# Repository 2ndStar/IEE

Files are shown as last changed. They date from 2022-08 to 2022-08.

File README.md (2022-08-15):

This is a PCB project for a 60% + XT column keyboard. It has a very specific fixed layout
1. Fixed split backspace
2. Fixed bottom row: 1.5u 1.25u 1.5u 2.75u 2.25u 1.5u 1.5u 1.25u 1.5u

There is a small issue with the "KC_Grave" key located at Row1 Column8.
Take a look at the schematic and fix it for yourself.

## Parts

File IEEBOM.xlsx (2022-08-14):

Comment | Designator | Footprint | LCSC Part # (Optional)
100nF | C3, C5, C6 | 805 | C49678
1uF | C4 | 805 | C28323
10uF | C7 | 805 | C15850
10K | R3, R4 | 805 | C17414
22 | R1, R2 | 805 | C17561
SWITCHING DIODE | D1,D2,D3,D4,D5,D6,D7,D8,D9,D10,D11,D12,D13,D14,D15,D16,D17,D18,D19,D20,D21,D22,D23,D24,D25,D26,D27,D28,D29,D30,D31,D32,D33,D34,D35,D36,D37,D38,D39,D40,D41,D42,D43,D44,D45,D46,D47,D48,D49,D50,D51,D52,D53,D54,D55,D56,D57,D58,D59,D60,D61,D62,D63,D64,D65,D66,D67,D68,D69,D70,D71,D72,D73,D74 | SOD-123 | C81598
16MHz | Y1 | 3225 | C13738
500mA | F1 | 1206 | C70076
22pF | C1, C2 | 805 | C1804
Button | SW1 | smdPushBtn | C318884
SM04B-SRSS-TB | J1 | SM04B-SRSS-TB | C371571
SRV05-4 | U2 | SOT-23-6L | C85364
500 | R5 | 805 | C2828857
1N4001W | D75 | SOD-123F | C162732
2.2k | R6 | 805 | C17520

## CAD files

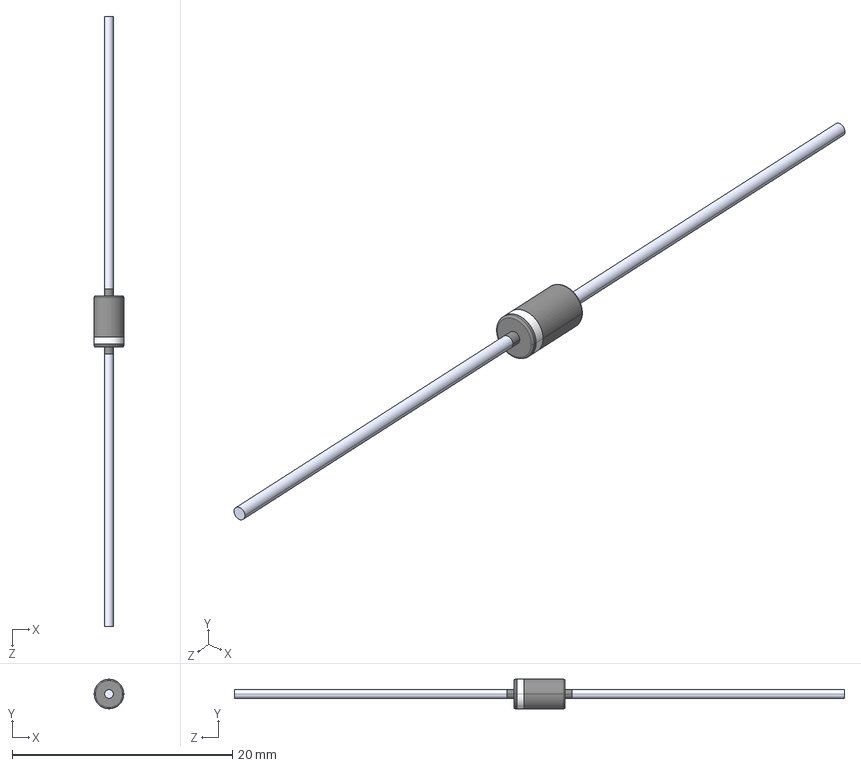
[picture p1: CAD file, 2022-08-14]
1N4001-T/1N4001-T.step
2.69 x 2.69 x 55.4 mm

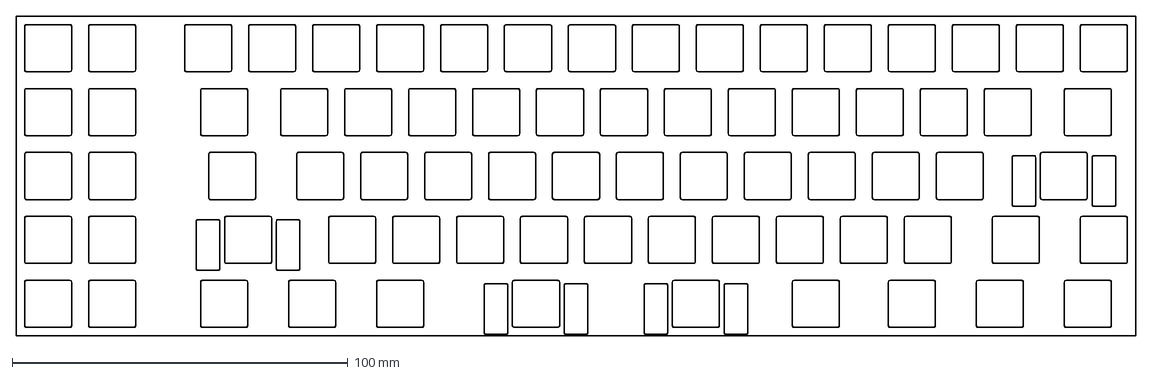
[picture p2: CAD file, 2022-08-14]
plateguide.dxf
333.4 x 95.2 mm

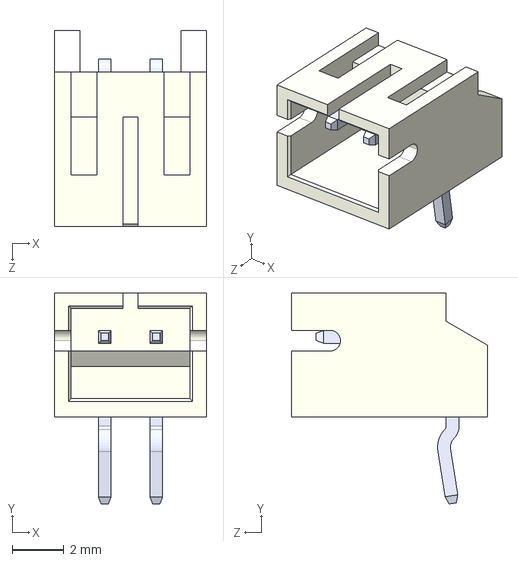
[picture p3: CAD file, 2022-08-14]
S2B-PH-K-S_LF__SN_/S2B-PH-K-S_LF__SN_.step
5.90 x 8.18 x 7.60 mm

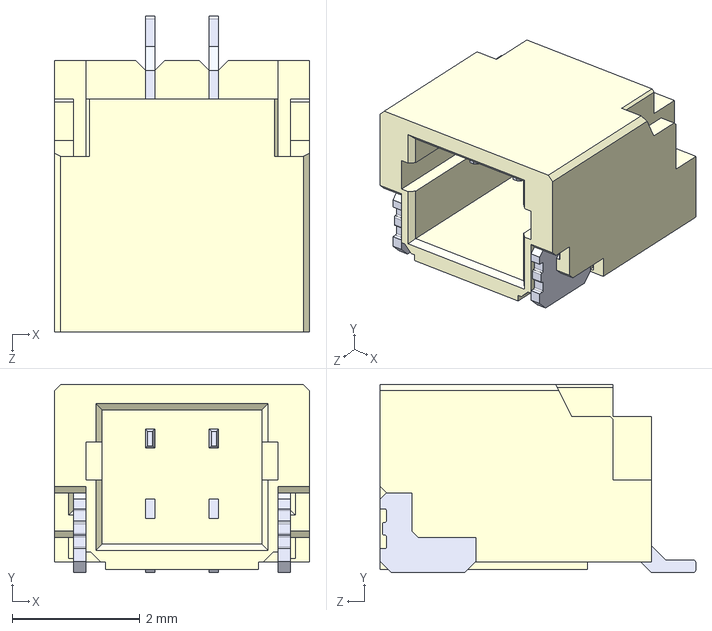
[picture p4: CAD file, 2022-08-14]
SM02B-SRSS-TB_LF__SN_/SM02B-SRSS-TB_LF__SN_.step
4.00 x 2.95 x 4.95 mm

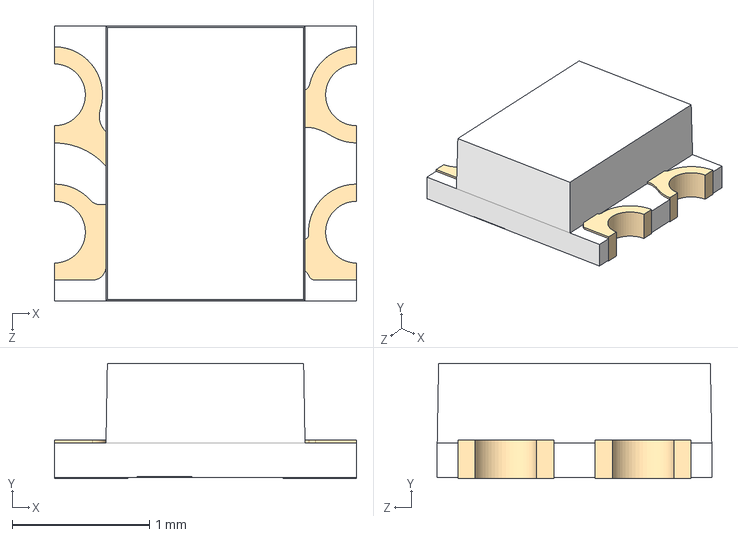
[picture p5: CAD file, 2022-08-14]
WS2812-2020/WS2812-2020.step
2.20 x 0.84 x 2.00 mm

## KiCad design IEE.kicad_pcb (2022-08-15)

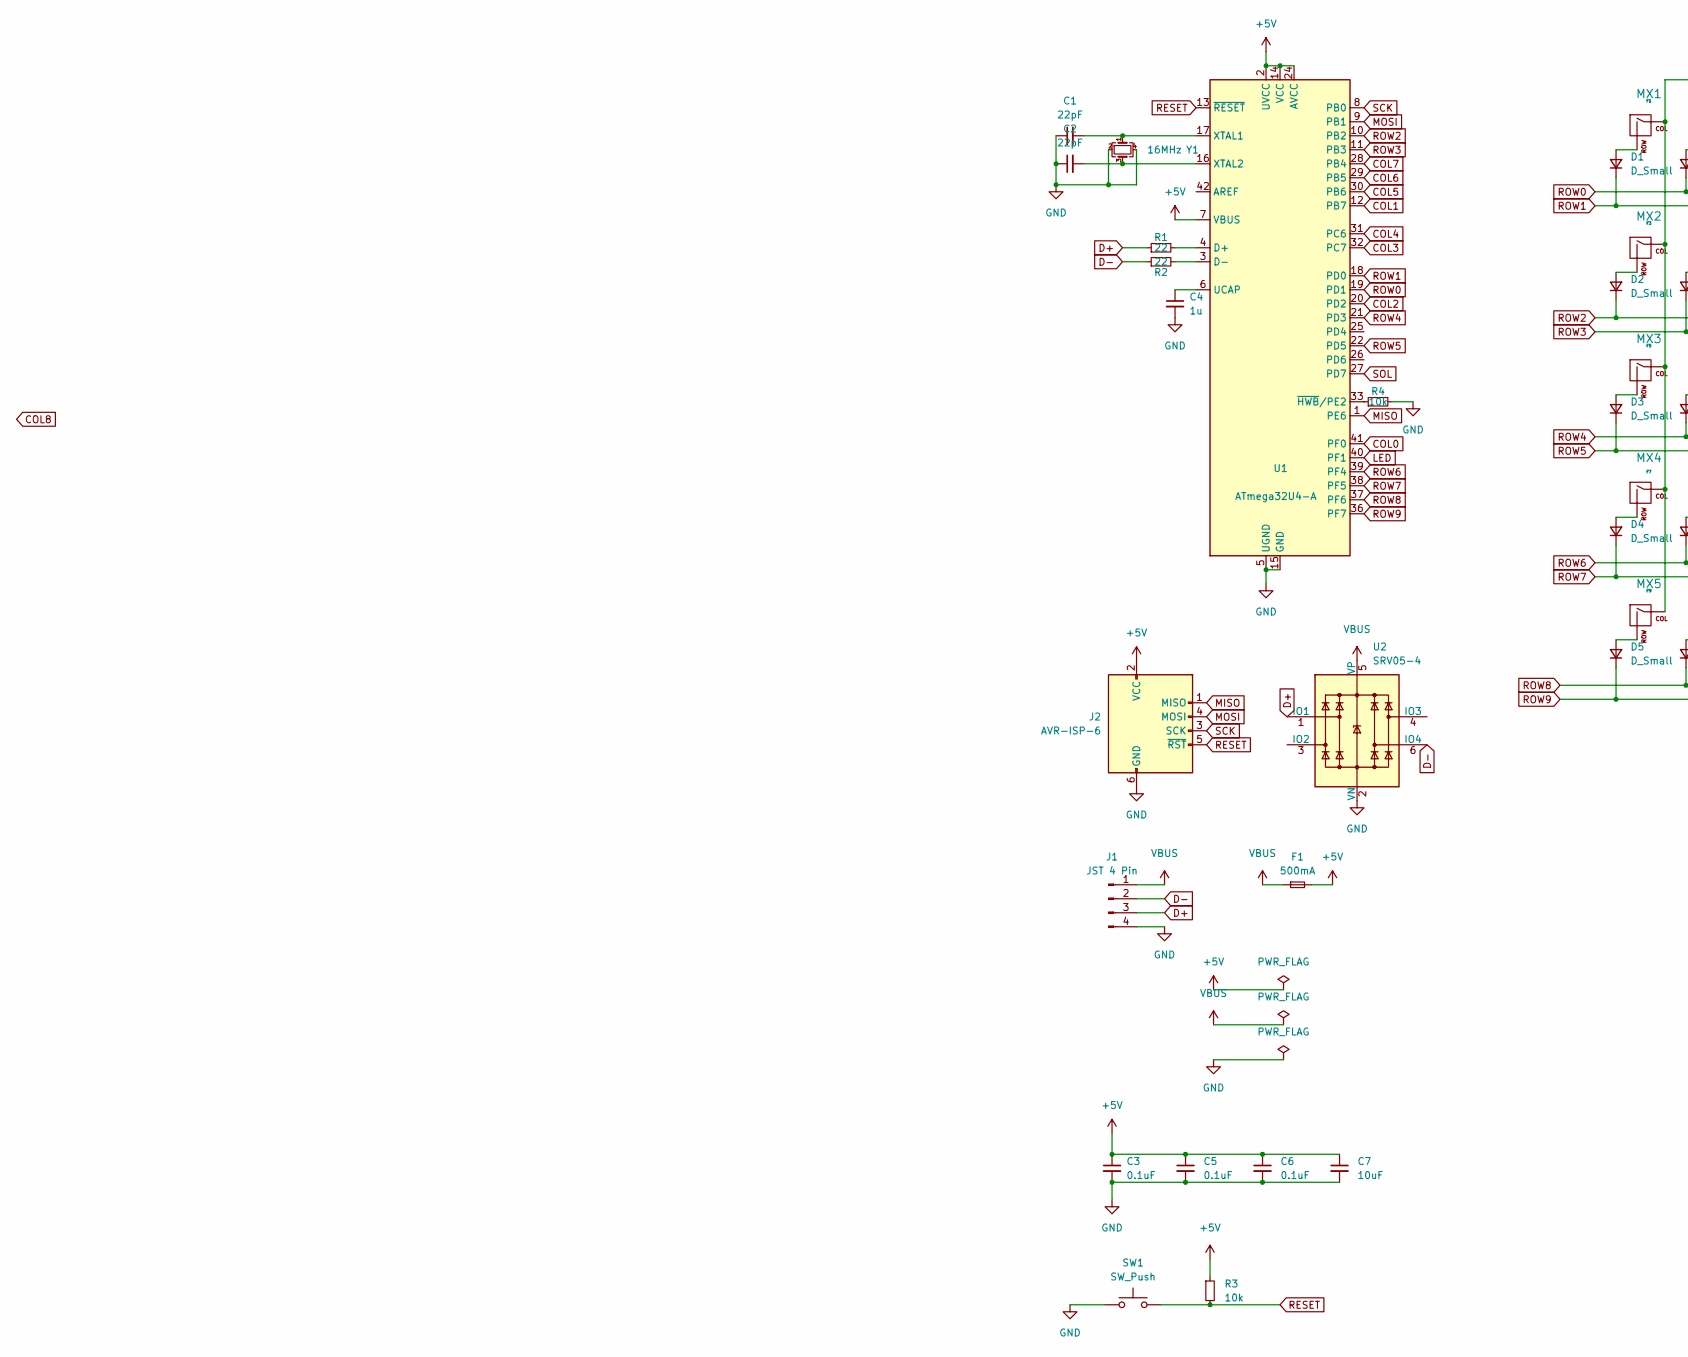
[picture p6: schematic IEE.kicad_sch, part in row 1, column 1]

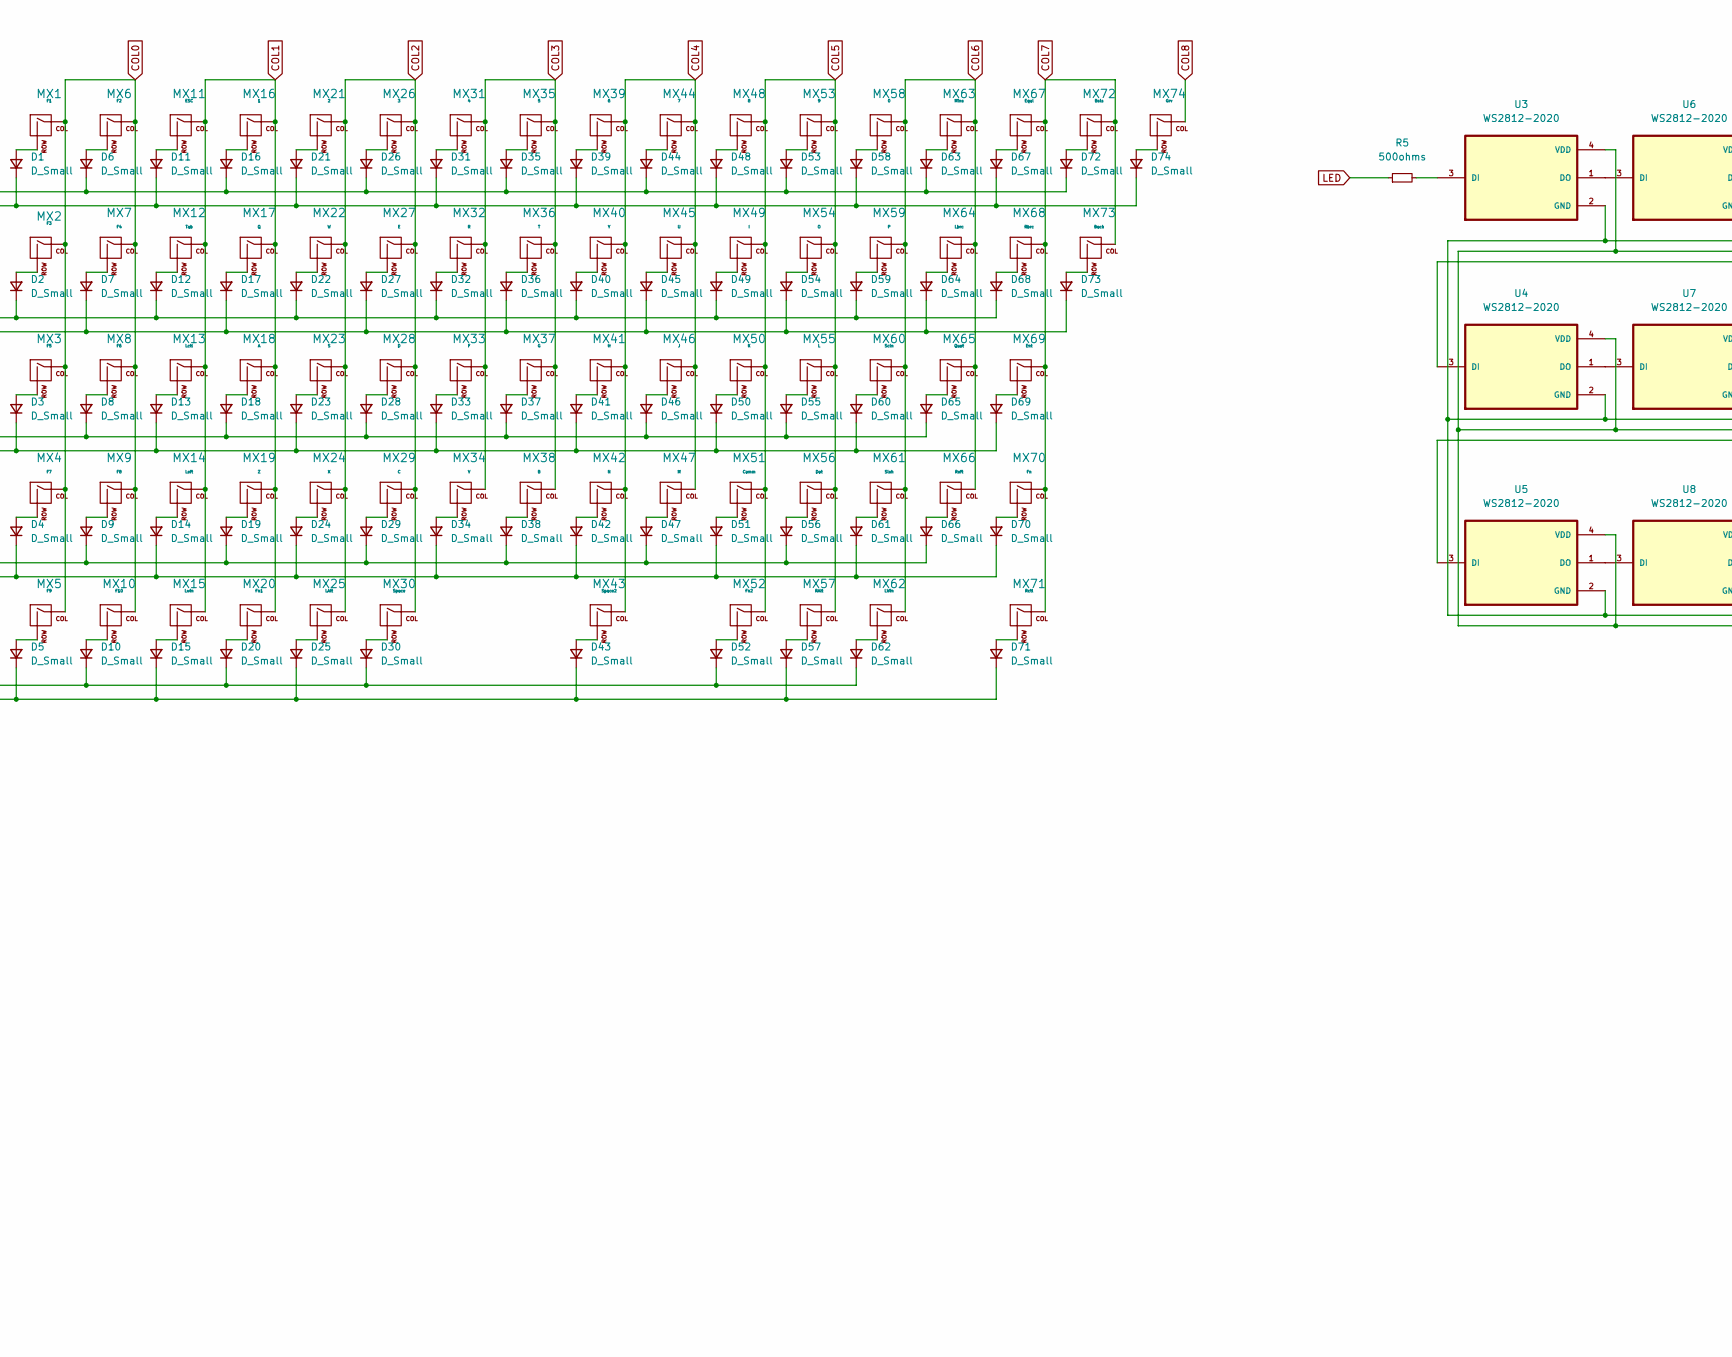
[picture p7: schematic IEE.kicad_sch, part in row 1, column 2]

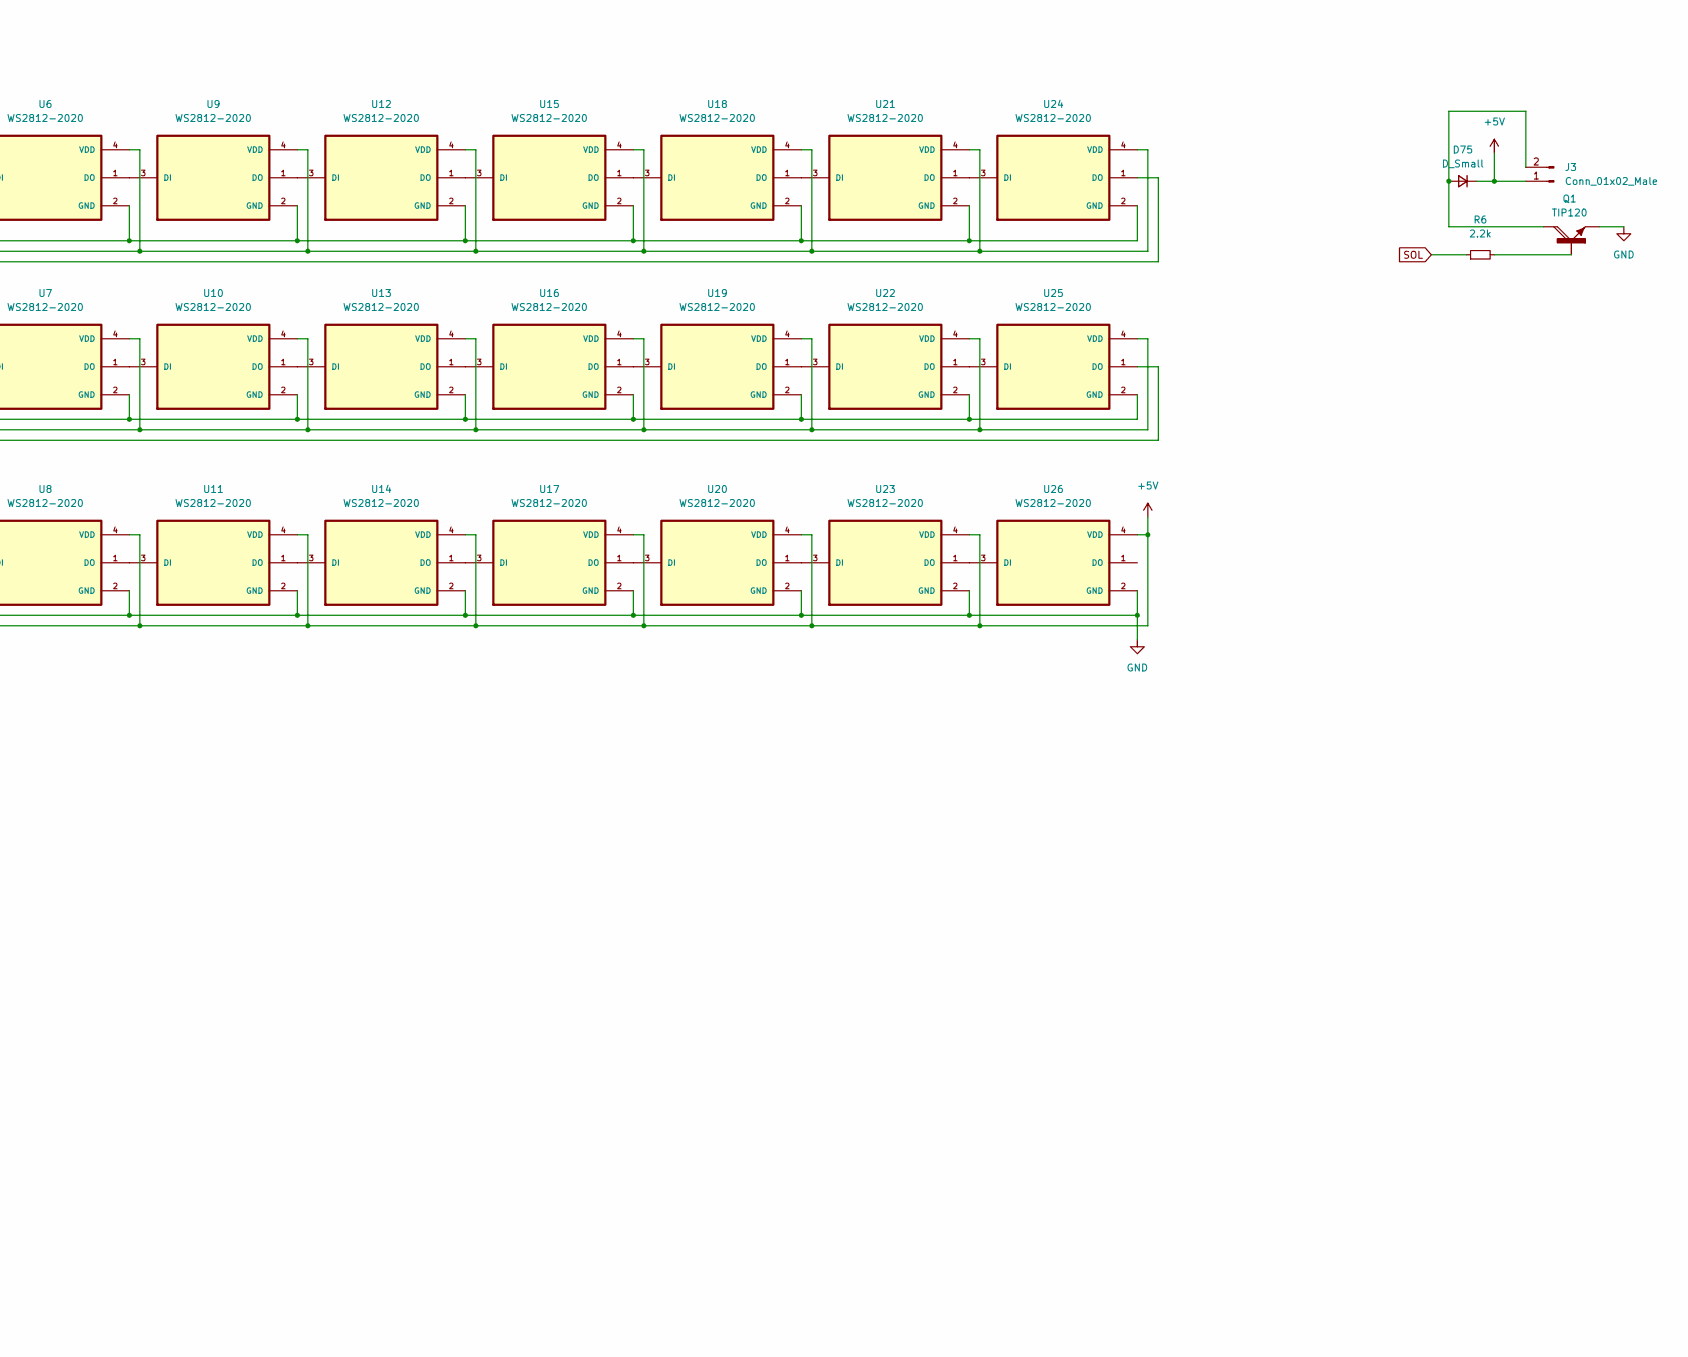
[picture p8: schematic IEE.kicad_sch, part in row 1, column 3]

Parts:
C1, C2: 22pF; C_0805_2012Metric
C3, C5, C6: 0.1uF; C_0805_2012Metric
C4: 1u; C_0805_2012Metric
C7: 10uF; C_0805_2012Metric
D1, D2, D3, D4, D5, D6, D7, D8, D9, D10, D11, D12, D13, D14, D15, D16, D17, D18, D19, D20, D21, D22, D23, D24, D25, D26, D27, D28, D29, D30, D31, D32, D33, D34, D35, D36, D37, D38, D39, D40, D41, D42, D43, D44, D45, D46, D47, D48, D49, D50, D51, D52, D53, D54, D55, D56, D57, D58, D59, D60, D61, D62, D63, D64, D65, D66, D67, D68, D69, D70, D71, D72, D73, D74: D_Small; D_SOD-123
D75: D_Small; D_SOD-123F
F1: 500mA; Fuse_1206_3216Metric
J1: JST 4 Pin; JST-SR-4
J2: AVR-ISP-6; ISP
J3: Conn_01x02_Male; JST_S2B-PH-K-S(LF)(SN)
MX1: F1; MXOnly-1U-NoLED
MX2: F3; MXOnly-1U-NoLED
MX3: F5; MXOnly-1U-NoLED
MX4: F7; MXOnly-1U-NoLED
MX5: F9; MXOnly-1U-NoLED
MX6: F2; MXOnly-1U-NoLED
MX7: F4; MXOnly-1U-NoLED
MX8: F6; MXOnly-1U-NoLED
MX9: F8; MXOnly-1U-NoLED
MX10: F10; MXOnly-1U-NoLED
MX11: ESC; MXOnly-1U-NoLED
MX12: Tab; MXOnly-1.5U-NoLED
MX13: Lctl; MXOnly-1.75U-NoLED
MX14: Lsft; MXOnly-2.25U-NoLED
MX15: Lwin; MXOnly-1.5U-NoLED
MX16: 1; MXOnly-1U-NoLED
MX17: Q; MXOnly-1U-NoLED
MX18: A; MXOnly-1U-NoLED
MX19: Z; MXOnly-1U-NoLED
MX20: Fn1; MXOnly-1.25U-NoLED
MX21: 2; MXOnly-1U-NoLED
MX22: W; MXOnly-1U-NoLED
MX23: S; MXOnly-1U-NoLED
MX24: X; MXOnly-1U-NoLED
MX25: LAlt; MXOnly-1.5U-NoLED
MX26: 3; MXOnly-1U-NoLED
MX27: E; MXOnly-1U-NoLED
MX28: D; MXOnly-1U-NoLED
MX29: C; MXOnly-1U-NoLED
MX30: Space; MXOnly-2.75U-ReversedStabilizers-NoLED
MX31: 4; MXOnly-1U-NoLED
MX32: R; MXOnly-1U-NoLED
MX33: F; MXOnly-1U-NoLED
MX34: V; MXOnly-1U-NoLED
MX35: 5; MXOnly-1U-NoLED
MX36: T; MXOnly-1U-NoLED
MX37: G; MXOnly-1U-NoLED
MX38: B; MXOnly-1U-NoLED
MX39: 6; MXOnly-1U-NoLED
MX40: Y; MXOnly-1U-NoLED
MX41: H; MXOnly-1U-NoLED
MX42: N; MXOnly-1U-NoLED
MX43: Space2; MXOnly-2.25U-ReversedStabilizers-NoLED
MX44: 7; MXOnly-1U-NoLED
MX45: U; MXOnly-1U-NoLED
MX46: J; MXOnly-1U-NoLED
MX47: M; MXOnly-1U-NoLED
MX48: 8; MXOnly-1U-NoLED
MX49: I; MXOnly-1U-NoLED
MX50: K; MXOnly-1U-NoLED
MX51: Comm; MXOnly-1U-NoLED
MX52: Fn2; MXOnly-1.5U-NoLED
MX53: 9; MXOnly-1U-NoLED
MX54: O; MXOnly-1U-NoLED
MX55: L; MXOnly-1U-NoLED
MX56: Dot; MXOnly-1U-NoLED
MX57: RAlt; MXOnly-1.5U-NoLED
MX58: 0; MXOnly-1U-NoLED
MX59: P; MXOnly-1U-NoLED
MX60: Scln; MXOnly-1U-NoLED
MX61: Slsh; MXOnly-1U-NoLED
MX62: LWin; MXOnly-1.25U-NoLED
MX63: Mins; MXOnly-1U-NoLED
MX64: Lbrc; MXOnly-1U-NoLED
MX65: Quot; MXOnly-1U-NoLED
MX66: Rsft; MXOnly-1.75U-NoLED
MX67: Equl; MXOnly-1U-NoLED
MX68: Rbrc; MXOnly-1U-NoLED
MX69: Ent; MXOnly-2.25U-NoLED
MX70: Fn; MXOnly-1U-NoLED
MX71: Rctl; MXOnly-1.5U-NoLED
MX72: Bsls; MXOnly-1U-NoLED
MX73: Back; MXOnly-1.5U-NoLED
MX74: Grv; MXOnly-1U-NoLED
Q1: TIP120; TO220AH
R1, R2: 22; R_0805_2012Metric
R3, R4: 10k; R_0805_2012Metric
R5: 500ohms; R_0805_2012Metric
R6: 2.2k; R_0805_2012Metric
SW1: SW_Push; SKQG-1155865
U1: ATmega32U4-A; TQFP-44_10x10mm_P0.8mm
U2: SRV05-4; SOT-23-6
U3, U4, U5, U6, U7, U8, U9, U10, U11, U12, U13, U14, U15, U16, U17, U18, U19, U20, U21, U22, U23, U24, U25, U26: WS2812-2020; LED_WS2812-2020
Y1: 16MHz; Crystal_SMD_3225-4Pin_3.2x2.5mm

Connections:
+5V: C3.1, C5.1, C6.1, C7.1, D75.1 (K), F1.2, J2.2 (VCC), J3.1, R3.1, U1.2 (UVCC), U1.7 (VBUS), U1.14 (VCC), U1.24 (AVCC), U1.34 (VCC), U1.44 (AVCC), U3.4 (VDD), U4.4 (VDD), U5.4 (VDD), U6.4 (VDD), U7.4 (VDD), U8.4 (VDD), U9.4 (VDD), U10.4 (VDD), U11.4 (VDD), U12.4 (VDD), U13.4 (VDD), U14.4 (VDD), U15.4 (VDD), U16.4 (VDD), U17.4 (VDD), U18.4 (VDD), U19.4 (VDD), U20.4 (VDD), U21.4 (VDD), U22.4 (VDD), U23.4 (VDD), U24.4 (VDD), U25.4 (VDD), U26.4 (VDD)
COL0: MX1.1 (COL), MX2.1 (COL), MX3.1 (COL), MX4.1 (COL), MX5.1 (COL), MX6.1 (COL), MX7.1 (COL), MX8.1 (COL), MX9.1 (COL), MX10.1 (COL), U1.41 (PF0)
COL1: MX11.1 (COL), MX12.1 (COL), MX13.1 (COL), MX14.1 (COL), MX15.1 (COL), MX16.1 (COL), MX17.1 (COL), MX18.1 (COL), MX19.1 (COL), MX20.1 (COL), U1.12 (PB7)
COL2: MX21.1 (COL), MX22.1 (COL), MX23.1 (COL), MX24.1 (COL), MX25.1 (COL), MX26.1 (COL), MX27.1 (COL), MX28.1 (COL), MX29.1 (COL), MX30.1 (COL), U1.20 (PD2)
COL3: MX31.1 (COL), MX32.1 (COL), MX33.1 (COL), MX34.1 (COL), MX35.1 (COL), MX36.1 (COL), MX37.1 (COL), MX38.1 (COL), U1.32 (PC7)
COL4: MX39.1 (COL), MX40.1 (COL), MX41.1 (COL), MX42.1 (COL), MX43.1 (COL), MX44.1 (COL), MX45.1 (COL), MX46.1 (COL), MX47.1 (COL), U1.31 (PC6)
COL5: MX48.1 (COL), MX49.1 (COL), MX50.1 (COL), MX51.1 (COL), MX52.1 (COL), MX53.1 (COL), MX54.1 (COL), MX55.1 (COL), MX56.1 (COL), MX57.1 (COL), U1.30 (PB6)
COL6: MX58.1 (COL), MX59.1 (COL), MX60.1 (COL), MX61.1 (COL), MX62.1 (COL), MX63.1 (COL), MX64.1 (COL), MX65.1 (COL), MX66.1 (COL), U1.29 (PB5)
COL7: MX67.1 (COL), MX68.1 (COL), MX69.1 (COL), MX70.1 (COL), MX71.1 (COL), MX72.1 (COL), MX73.1 (COL), U1.28 (PB4)
COL8: MX74.1 (COL)
D+: J1.3, R1.1, U2.1 (IO1)
D-: J1.2, R2.1, U2.6 (IO4)
GND: C1.1, C2.1, C3.2, C4.2, C5.2, C6.2, C7.2, J1.4, J2.6 (GND), Q1.E, R4.2, SW1.1, U1.5 (UGND), U1.15 (GND), U1.23 (GND), U1.35 (GND), U1.43 (GND), U2.2 (VN), U3.2 (GND), U4.2 (GND), U5.2 (GND), U6.2 (GND), U7.2 (GND), U8.2 (GND), U9.2 (GND), U10.2 (GND), U11.2 (GND), U12.2 (GND), U13.2 (GND), U14.2 (GND), U15.2 (GND), U16.2 (GND), U17.2 (GND), U18.2 (GND), U19.2 (GND), U20.2 (GND), U21.2 (GND), U22.2 (GND), U23.2 (GND), U24.2 (GND), U25.2 (GND), U26.2 (GND), Y1.2, Y1.4
LED: R5.1, U1.40 (PF1)
MISO: J2.1 (MISO), U1.1 (PE6)
MOSI: J2.4 (MOSI), U1.9 (PB1)
unnamed: C1.2, U1.17 (XTAL1), Y1.1
unnamed: C2.2, U1.16 (XTAL2), Y1.3
unnamed: C4.1, U1.6 (UCAP)
unnamed: D1.2 (A), MX1.2 (ROW)
unnamed: D2.2 (A), MX2.2 (ROW)
unnamed: D3.2 (A), MX3.2 (ROW)
unnamed: D4.2 (A), MX4.2 (ROW)
unnamed: D5.2 (A), MX5.2 (ROW)
unnamed: D6.2 (A), MX6.2 (ROW)
unnamed: D7.2 (A), MX7.2 (ROW)
unnamed: D8.2 (A), MX8.2 (ROW)
unnamed: D9.2 (A), MX9.2 (ROW)
unnamed: D10.2 (A), MX10.2 (ROW)
unnamed: D11.2 (A), MX11.2 (ROW)
unnamed: D12.2 (A), MX12.2 (ROW)
unnamed: D13.2 (A), MX13.2 (ROW)
unnamed: D14.2 (A), MX14.2 (ROW)
unnamed: D15.2 (A), MX15.2 (ROW)
unnamed: D16.2 (A), MX16.2 (ROW)
unnamed: D17.2 (A), MX17.2 (ROW)
unnamed: D18.2 (A), MX18.2 (ROW)
unnamed: D19.2 (A), MX19.2 (ROW)
unnamed: D20.2 (A), MX20.2 (ROW)
unnamed: D21.2 (A), MX21.2 (ROW)
unnamed: D22.2 (A), MX22.2 (ROW)
unnamed: D23.2 (A), MX23.2 (ROW)
unnamed: D24.2 (A), MX24.2 (ROW)
unnamed: D25.2 (A), MX25.2 (ROW)
unnamed: D26.2 (A), MX26.2 (ROW)
unnamed: D27.2 (A), MX27.2 (ROW)
unnamed: D28.2 (A), MX28.2 (ROW)
unnamed: D29.2 (A), MX29.2 (ROW)
unnamed: D30.2 (A), MX30.2 (ROW)
unnamed: D31.2 (A), MX31.2 (ROW)
unnamed: D32.2 (A), MX32.2 (ROW)
unnamed: D33.2 (A), MX33.2 (ROW)
unnamed: D34.2 (A), MX34.2 (ROW)
unnamed: D35.2 (A), MX35.2 (ROW)
unnamed: D36.2 (A), MX36.2 (ROW)
unnamed: D37.2 (A), MX37.2 (ROW)
unnamed: D38.2 (A), MX38.2 (ROW)
unnamed: D39.2 (A), MX39.2 (ROW)
unnamed: D40.2 (A), MX40.2 (ROW)
unnamed: D41.2 (A), MX41.2 (ROW)
unnamed: D42.2 (A), MX42.2 (ROW)
unnamed: D43.2 (A), MX43.2 (ROW)
unnamed: D44.2 (A), MX44.2 (ROW)
unnamed: D45.2 (A), MX45.2 (ROW)
unnamed: D46.2 (A), MX46.2 (ROW)
unnamed: D47.2 (A), MX47.2 (ROW)
unnamed: D48.2 (A), MX48.2 (ROW)
unnamed: D49.2 (A), MX49.2 (ROW)
unnamed: D50.2 (A), MX50.2 (ROW)
unnamed: D51.2 (A), MX51.2 (ROW)
unnamed: D52.2 (A), MX52.2 (ROW)
unnamed: D53.2 (A), MX53.2 (ROW)
unnamed: D54.2 (A), MX54.2 (ROW)
unnamed: D55.2 (A), MX55.2 (ROW)
unnamed: D56.2 (A), MX56.2 (ROW)
unnamed: D57.2 (A), MX57.2 (ROW)
unnamed: D58.2 (A), MX58.2 (ROW)
unnamed: D59.2 (A), MX59.2 (ROW)
unnamed: D60.2 (A), MX60.2 (ROW)
unnamed: D61.2 (A), MX61.2 (ROW)
unnamed: D62.2 (A), MX62.2 (ROW)
unnamed: D63.2 (A), MX63.2 (ROW)
unnamed: D64.2 (A), MX64.2 (ROW)
unnamed: D65.2 (A), MX65.2 (ROW)
unnamed: D66.2 (A), MX66.2 (ROW)
unnamed: D67.2 (A), MX67.2 (ROW)
unnamed: D68.2 (A), MX68.2 (ROW)
unnamed: D69.2 (A), MX69.2 (ROW)
unnamed: D70.2 (A), MX70.2 (ROW)
unnamed: D71.2 (A), MX71.2 (ROW)
unnamed: D72.2 (A), MX72.2 (ROW)
unnamed: D73.2 (A), MX73.2 (ROW)
unnamed: D74.2 (A), MX74.2 (ROW)
unnamed: D75.2 (A), J3.2, Q1.C
unnamed: Q1.B, R6.2
unnamed: R1.2, U1.4 (D+)
unnamed: R2.2, U1.3 (D-)
unnamed: R4.1, U1.33 (~HWB/PE2)
unnamed: R5.2, U3.3 (DI)
unnamed: U3.1 (DO), U6.3 (DI)
unnamed: U4.1 (DO), U7.3 (DI)
unnamed: U5.1 (DO), U8.3 (DI)
unnamed: U6.1 (DO), U9.3 (DI)
unnamed: U10.1 (DO), U13.3 (DI)
unnamed: U7.1 (DO), U10.3 (DI)
unnamed: U11.1 (DO), U14.3 (DI)
unnamed: U8.1 (DO), U11.3 (DI)
unnamed: U12.1 (DO), U15.3 (DI)
unnamed: U9.1 (DO), U12.3 (DI)
unnamed: U13.1 (DO), U16.3 (DI)
unnamed: U14.1 (DO), U17.3 (DI)
unnamed: U15.1 (DO), U18.3 (DI)
unnamed: U16.1 (DO), U19.3 (DI)
unnamed: U17.1 (DO), U20.3 (DI)
unnamed: U18.1 (DO), U21.3 (DI)
unnamed: U19.1 (DO), U22.3 (DI)
unnamed: U20.1 (DO), U23.3 (DI)
unnamed: U21.1 (DO), U24.3 (DI)
unnamed: U22.1 (DO), U25.3 (DI)
unnamed: U23.1 (DO), U26.3 (DI)
unnamed: U4.3 (DI), U24.1 (DO)
unnamed: U5.3 (DI), U25.1 (DO)
RESET: J2.5 (~RST), R3.2, SW1.2, U1.13 (~RESET)
ROW0: D6.1 (K), D16.1 (K), D26.1 (K), D35.1 (K), D44.1 (K), D53.1 (K), D63.1 (K), D72.1 (K), U1.19 (PD1)
ROW1: D1.1 (K), D11.1 (K), D21.1 (K), D31.1 (K), D39.1 (K), D48.1 (K), D58.1 (K), D67.1 (K), D74.1 (K), U1.18 (PD0)
ROW2: D2.1 (K), D12.1 (K), D22.1 (K), D32.1 (K), D40.1 (K), D49.1 (K), D59.1 (K), D68.1 (K), U1.10 (PB2)
ROW3: D7.1 (K), D17.1 (K), D27.1 (K), D36.1 (K), D45.1 (K), D54.1 (K), D64.1 (K), D73.1 (K), U1.11 (PB3)
ROW4: D8.1 (K), D18.1 (K), D28.1 (K), D37.1 (K), D46.1 (K), D55.1 (K), D65.1 (K), U1.21 (PD3)
ROW5: D3.1 (K), D13.1 (K), D23.1 (K), D33.1 (K), D41.1 (K), D50.1 (K), D60.1 (K), D69.1 (K), U1.22 (PD5)
ROW6: D9.1 (K), D19.1 (K), D29.1 (K), D38.1 (K), D47.1 (K), D56.1 (K), D66.1 (K), U1.39 (PF4)
ROW7: D4.1 (K), D14.1 (K), D24.1 (K), D34.1 (K), D42.1 (K), D51.1 (K), D61.1 (K), D70.1 (K), U1.38 (PF5)
ROW8: D10.1 (K), D20.1 (K), D30.1 (K), D52.1 (K), D62.1 (K), U1.37 (PF6)
ROW9: D5.1 (K), D15.1 (K), D25.1 (K), D43.1 (K), D57.1 (K), D71.1 (K), U1.36 (PF7)
SCK: J2.3 (SCK), U1.8 (PB0)
SOL: R6.1, U1.27 (PD7)
VBUS: F1.1, J1.1, U2.5 (VP)

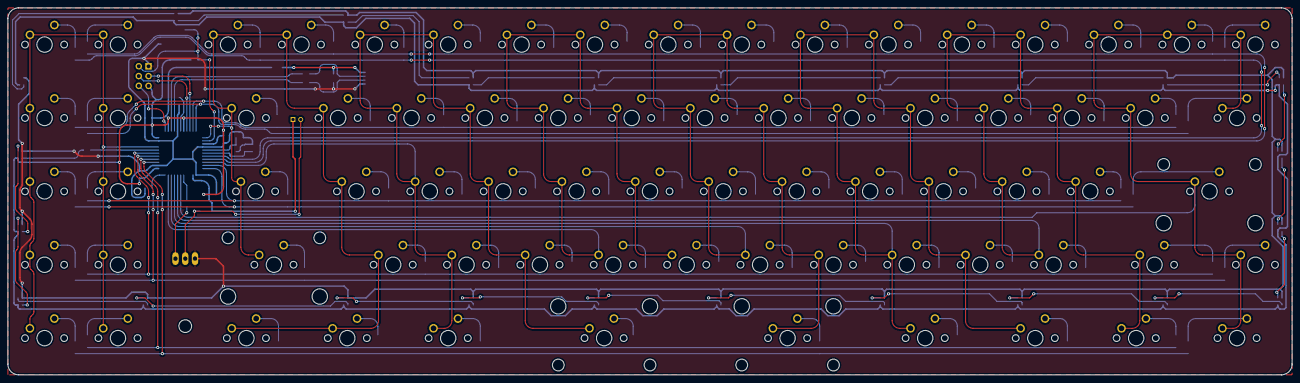
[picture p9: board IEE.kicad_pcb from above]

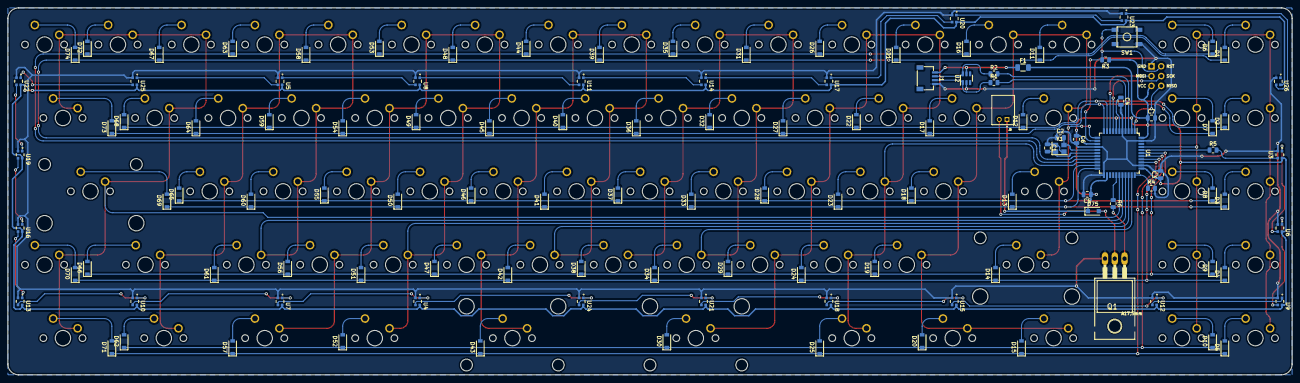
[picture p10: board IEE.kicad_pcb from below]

Board: 2 copper layers, 333.4 x 95.2 mm, 195 parts (121 on the bottom side), 135 nets.

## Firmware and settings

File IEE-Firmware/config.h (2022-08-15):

#pragma once

#include "config_common.h"

/* USB Device descriptor parameter */
#define VENDOR_ID       0x4A54
#define PRODUCT_ID      0x5052  
#define DEVICE_VER      0x0001
#define MANUFACTURER    jaydenta8
#define PRODUCT         IEE
#define DESCRIPTION     QMK-programmable 74 keys with separated arrows keys

/* key matrix size */
#define MATRIX_ROWS 10
#define MATRIX_COLS 9

/*
 * Keyboard Matrix Assignments
 *
 * Change this to how you wired your keyboard
 * COLS: AVR pins used for columns, left to right
 * ROWS: AVR pins used for rows, top to bottom
 * DIODE_DIRECTION: COL2ROW = COL = Anode (+), ROW = Cathode (-, marked on diode)
 *                  ROW2COL = ROW = Anode (+), COL = Cathode (-, marked on diode)
 *
 */


/* key matrix size */
#define MATRIX_ROWS 10
#define MATRIX_COLS 9

/*
 * Keyboard Matrix Assignments
 *
 * Change this to how you wired your keyboard
 * COLS: AVR pins used for columns, left to right
 * ROWS: AVR pins used for rows, top to bottom
 * DIODE_DIRECTION: COL2ROW = COL = Anode (+), ROW = Cathode (-, marked on diode)
 *                  ROW2COL = ROW = Anode (+), COL = Cathode (-, marked on diode)
 *
 */

#define MATRIX_ROW_PINS {D1, D0, B2, B3, D3, D5, F4, F5, F6, F7}
#define MATRIX_COL_PINS {F0, B7, D2, C7, C6, B6, B5, B4, D4}
#define UNUSED_PINS

/* COL2ROW, ROW2COL*/
#define DIODE_DIRECTION COL2ROW

/* Debounce reduces chatter (unintended double-presses) - set 0 if debouncing is not needed */
#define DEBOUNCE 5

/* Mechanical locking support. Use KC_LCAP, KC_LNUM or KC_LSCR instead in keymap */
#define LOCKING_SUPPORT_ENABLE
/* Locking resynchronize hack */
#define LOCKING_RESYNC_ENABLE

#define RGB_DI_PIN F1
#define RGBLIGHT_ANIMATIONS
#define RGBLED_NUM 24
#define RGBLIGHT_HUE_STEP 8
#define RGBLIGHT_SAT_STEP 8
#define RGBLIGHT_VAL_STEP 8
#define RGBLIGHT_LIMIT_VAL 200
#define RGBLIGHT_SLEEP // RGB will turn off when PC is put to sleep

#define SOLENOID_PIN D7
#define SOLENOID_DEFAULT_DWELL 12 
#define SOLENOID_MAX_DWELL 100
#define SOLENOID_MIN_DWELL 4
#define SOLENOID_DWELL_STEP_SIZE 1

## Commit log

2022-08-14 Initial commit of already made PCB
    [1N4001-T.step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]
2022-08-15 Add Firmware VIAL and QMK in IEE-Firmware folder
    [IEE.kicad_pcb, IEE.kicad_sch]
